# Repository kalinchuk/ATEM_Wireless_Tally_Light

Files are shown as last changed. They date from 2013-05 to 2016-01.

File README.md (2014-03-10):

# ATEM Wireless Tally Light

Wireless tally light system for ATEM switchers.

## Setup and Configuration

Note: We're assuming that you have a transmitter board with the Arduino Ethernet and also a receiver board with a JeeNode. If not, visit [http://kvitko.com/tally](http://kvitko.com/tally).

1.  Copy the dependent libraries from the project's libraries directory to your systems Arduino libraries directory. You may need to overwrite some of the libraries.
1.  Upload `ATEM_Tally_Receiver.ino` to your receiver node.
1.  Upload `ATEM_Tally_Transmitter.ino` to your transmitter.
1.  Connect the transmitter to the same network as the ATEM switcher and power it on (it may take a minute to connect to ATEM).
1.  Set the node # on your receiver using the DIP pins. It will blink the node # on power-on.

Once connected, the receiver will light up RED if on PROGRAM and GREEN if on PREVIEW.

## Transmitter

A transmitter transmits ATEM PROGRAM and PREVIEW camera numbers using an RF12 radio.

### Default Settings

	IP address		: 192.168.1.234
	Mac address 	: DE:AD:BE:EF:FE:ED
	Switcher IP		: 192.168.1.240
	Switcher PORT	: 49910

The settings can be modified using the web interface [http://192.168.1.234/](http://192.168.1.234/) or reset using the RESET button on the transmitter.

### LED States

The following are transmitter LED states:

	RED 		: Not connected to network (or ATEM switcher)
	BLUE 		: Connected to ATEM switcher
	RED BLINK	: Radio signal sent

## Receiver

A receiver receives radio signals from the transmitter and triggers either the PROGRAM LED or the PREVIEW LED according to the transmitter and ATEM.

### LED States

The following are receiver LED states:

	POWER-ON BLUE BLINK	: Blinks node # or rapidly for test mode
	CONSTANT BLUE BLINK	: In test mode (receiving radio signal)
	RED					: Node # is on PROGRAM
	GREEN				: Node # is on PREVIEW

### Test Mode

Setting the receiver's node # to 0 (all DIP pins off) will switch it to _test mode_. When in _test mode_ the receiver will blink BLUE every 1 second if it's receiving a radio signal. On power-on in _test mode_ the LED will blink BLUE rapidly for a second or so.

### Node DIP Pins

The node DIP pins are binary-based. For example, when the DIP pins are `0110`, the node # is `5`.

Note: The receiver needs to be restarted whenever the node # is changed.

## Library Modifications

The RF12 library was slightly modified to allow the Arduino Ethernet to support both the Ethernet and the RF12 radio. Since Ethernet and the radio both use the same `SS_BIT`, they will conflict with each other. Leave Ethernet as it is and modify the RF12 library only. 

Note: There is a new class called `RF12Mod` which is a copy of `RF12` with slight modifications.

## Credits

Based on the [Arduino ATEM Library](https://github.com/kasperskaarhoj/Arduino-Library-for-ATEM-Switchers)

## Contributing

We welcome any contributions and bug fixes. Feel free to send pull requests.

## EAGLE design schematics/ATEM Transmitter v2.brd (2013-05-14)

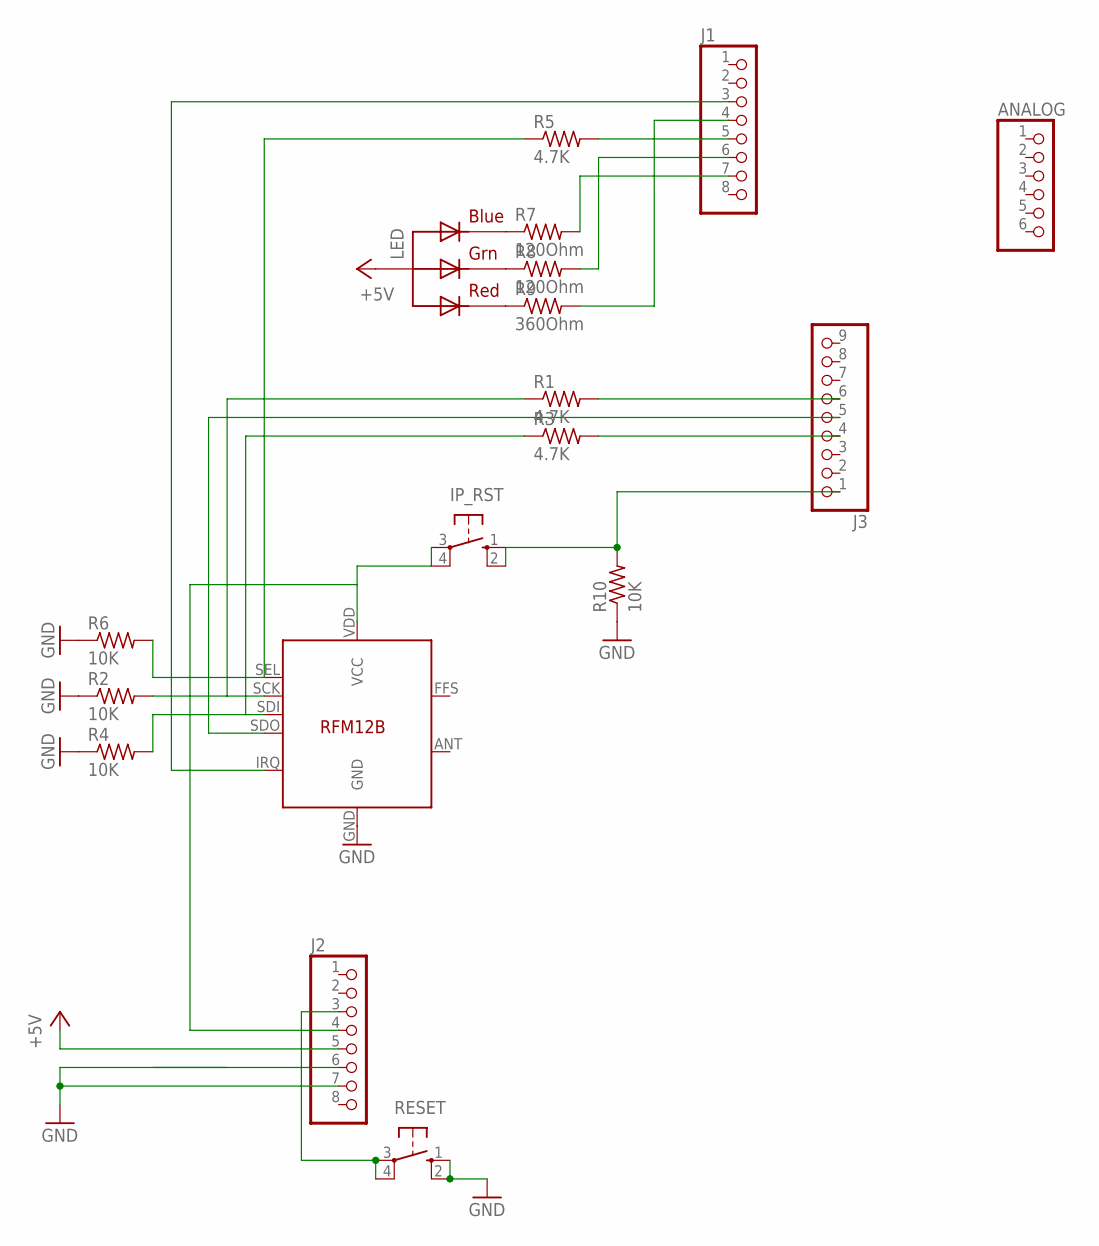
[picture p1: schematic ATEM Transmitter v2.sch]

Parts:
ANALOG: PINHD-1X6; 1X06
IP_RST: 10-XX; B3F-10XX
J1, J2: PINHD-1X8TH; 1X08-TH
J3: PINHD-1X9; 1X09
LED: RGBLED_CA-5MM; LED5MMRGB
R1, R3, R5: 4.7K; R0805
R2, R4, R6, R10: 10K; R0805
R7, R8: 120Ohm; R0805
R9: 360Ohm; R0805
RESET: 10-XX; B3F-10XX
U$2: RFM12B; LH-LIBRARY_RFM12B

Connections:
+5V: J2.5, LED.2 (VCC)
GND: J2.7, R2.1, R4.1, R6.1, R10.1, RESET.1 (S), RESET.2 (S1), U$2.GND
unnamed: IP_RST.3, IP_RST.4 (P1), J2.4, U$2.VDD (VCC)
unnamed: J3.6, R1.2
unnamed: R1.1, R2.2, U$2.SCK
unnamed: J1.3, U$2.IRQ
unnamed: R3.1, R4.2, U$2.SDI
unnamed: J3.4, R3.2
unnamed: J3.5, U$2.SDO
unnamed: R5.1, R6.2, U$2.SEL
unnamed: J1.5, R5.2
unnamed: LED.4 (BLUE), R7.1
unnamed: LED.3 (GREEN), R8.1
unnamed: LED.1 (RED), R9.1
unnamed: J1.4, R9.2
unnamed: IP_RST.1 (S), IP_RST.2 (S1), J3.1, R10.2
unnamed: J1.7, R7.2
unnamed: J1.6, R8.2
RESET: J2.3, RESET.3, RESET.4 (P1)

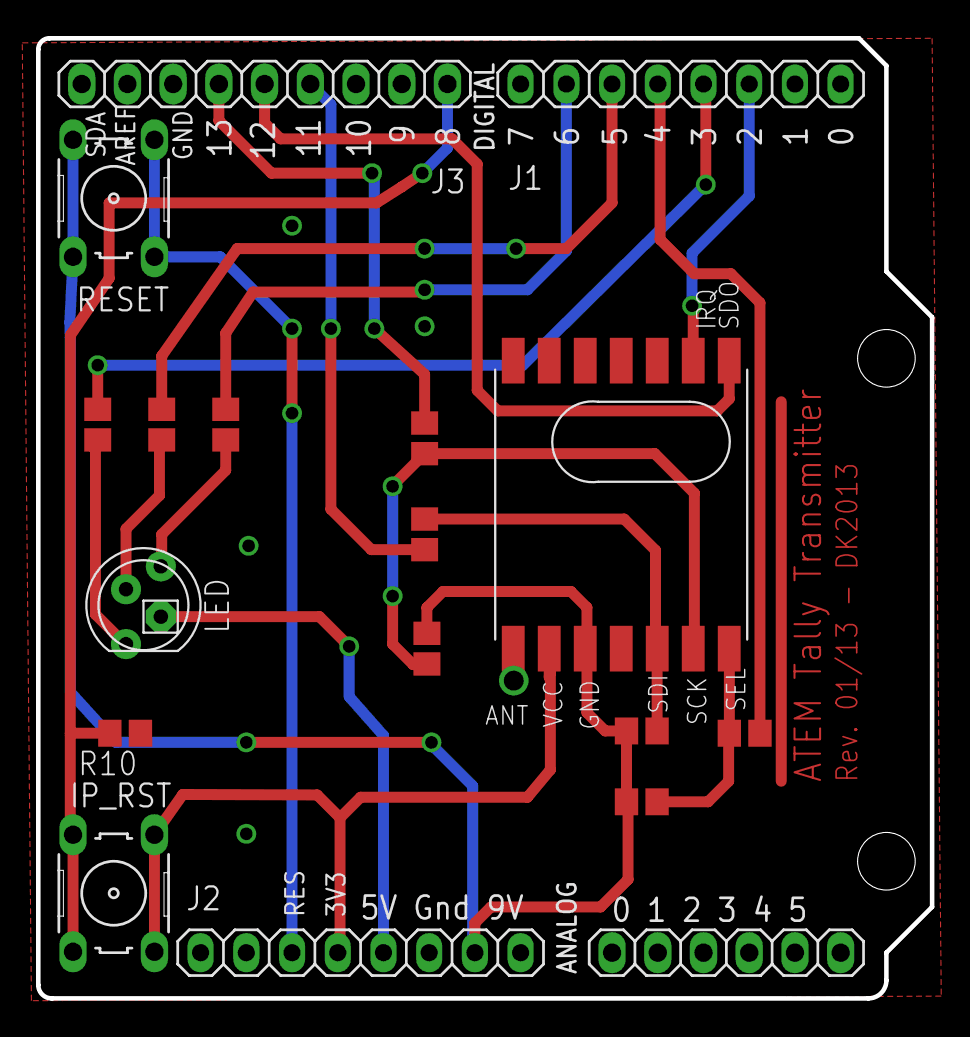
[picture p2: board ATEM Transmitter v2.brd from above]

Board: 2 copper layers, 49.7 x 53.3 mm, 18 parts (0 on the bottom side), 19 nets.

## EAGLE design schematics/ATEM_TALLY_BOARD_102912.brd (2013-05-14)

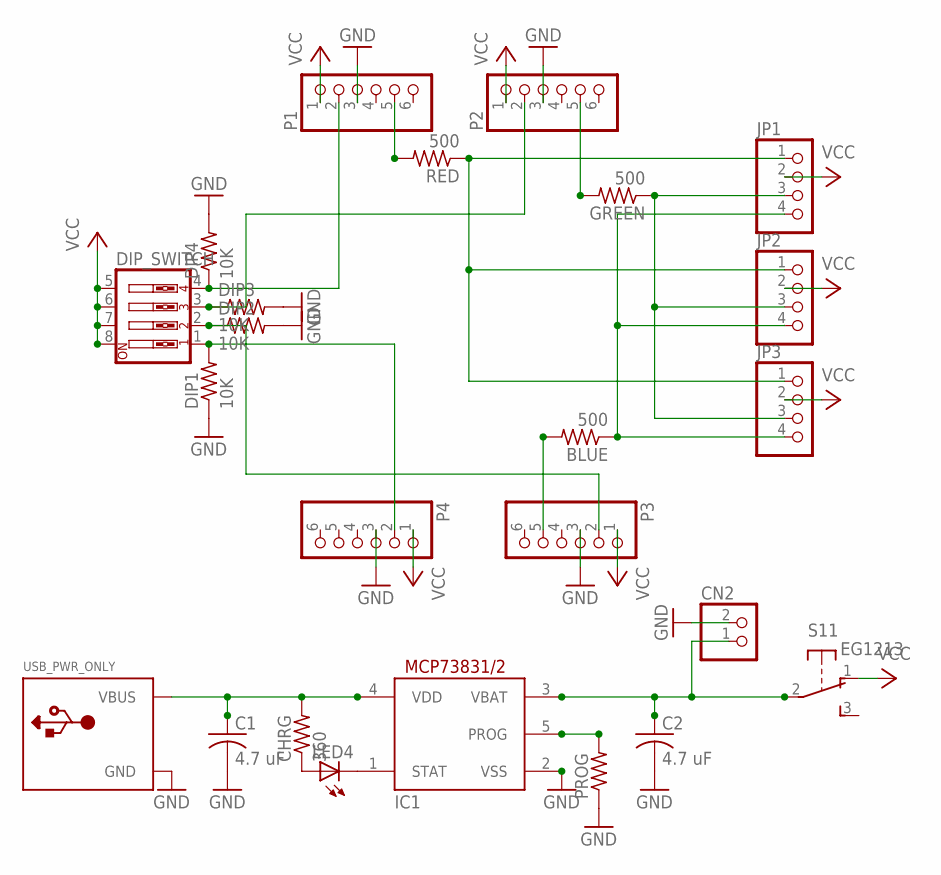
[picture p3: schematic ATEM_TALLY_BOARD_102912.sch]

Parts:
BLUE: 500; R0805
C1, C2: 4.7 uF; C0805K
CHRG: 360; R0805
CN2: JST_2PIN-SMT-RA; JST-PH-2-SMT-RA
DIP1, DIP2, DIP3, DIP4: 10K; R0805
DIP_SWITCH: SW_DIP-4; EDG-04
GREEN: 500; R0805
IC1: MCP73831/OT; SOT23-5L
JP1, JP2, JP3: PINHD-1X4; 1X04
LED4: LED3MM
P1, P2, P3, P4: PINHD-1X6CB; 1X06-CLEANBIG
PROG: R-US_R0805; R0805
RED: 500; R0805
S1: EG1213
USB_PWR_ONLY: USB-PWR-NOSILK; USB-MINIB-THM-MOLEX-PWRONLY-NOSILK

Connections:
BLUE: BLUE.1, JP1.4, JP2.4, JP3.4
GND: C1.2, C2.2, CN2.2 (1), DIP1.1, DIP2.2, DIP3.2, DIP4.2, IC1.2 (VSS), P1.3, P2.3, P3.3, P4.3, PROG.1, USB_PWR_ONLY.GND
GREEN: GREEN.1, JP1.3, JP2.3, JP3.3
unnamed: P1.5, RED.2
unnamed: GREEN.2, P2.5
unnamed: BLUE.2, P3.5
unnamed: C1.1, CHRG.2, IC1.4 (VDD), USB_PWR_ONLY.VBUS
unnamed: DIP4.1, DIP_SWITCH.4, P1.2
unnamed: DIP3.1, DIP_SWITCH.3, P2.2
unnamed: DIP2.1, DIP_SWITCH.2, P3.2
unnamed: DIP1.2, DIP_SWITCH.1, P4.2
unnamed: IC1.1 (STAT), LED4.K (C)
unnamed: CHRG.1, LED4.A
unnamed: IC1.5 (PROG), PROG.2
unnamed: C2.1, CN2.1 (2), IC1.3 (VBAT), S1.2
RED: JP1.1, JP2.1, JP3.1, RED.1
VCC: DIP_SWITCH.5, DIP_SWITCH.6, DIP_SWITCH.7, DIP_SWITCH.8, JP1.2, JP2.2, JP3.2, P1.1, P2.1, P3.1, P4.1, S1.1 (O)

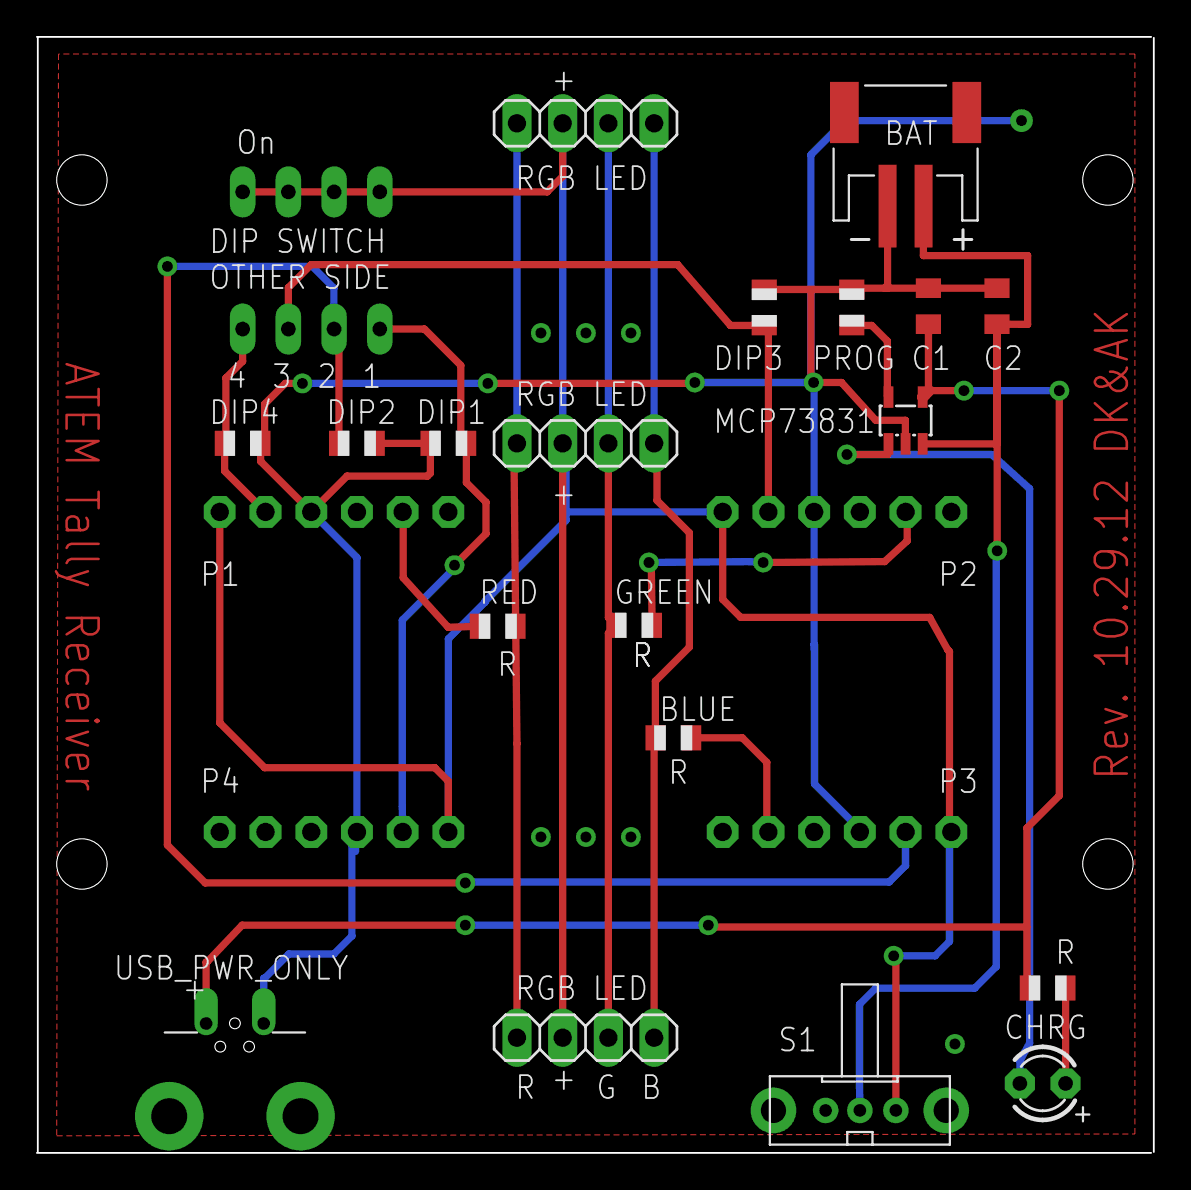
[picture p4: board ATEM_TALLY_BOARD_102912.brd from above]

Board: 2 copper layers, 62.0 x 62.0 mm, 24 parts (1 on the bottom side), 17 nets.

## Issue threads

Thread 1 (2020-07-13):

Misuse of Analog/digital pin functions

mwsfreak, 2020-07-13:
There seems to be a major misunderstanding in the use of AnalogWrite and DigitalWrite functions in ATEM_Tally_Receiver.ino

```C
int PROGRAM_PIN = A0;
int PREVIEW_PIN = A1;
int POWER_PIN = A2;
```
Led pins are set to Analog Input pins (l. 4+7+10). These pins are also capable of outputting digital signals, however not PWM signals.

```C
analogWrite(PROGRAM_PIN, 1023);
analogWrite(PREVIEW_PIN, 1023);
analogWrite(POWER_PIN, 1023);
```
Later (l. 50-52), an attempt is made to apparently output af PWM signal on these same pins.

```C
digitalWrite(PREVIEW_PIN, 1023);
digitalWrite(PROGRAM_PIN, 1023);
digitalWrite(POWER_PIN, 1023);
```
Further down, one attempts to write a value to a digital pin. The digitalwrite function only accepts HIGH and LOW.

The methods used probably works, but it seems quite far from the intended use of the functions.

kalinchuk, 2020-07-13:
@mwsfreak It may be a mistake. This repo is not being actively maintained. If you create a tested PR, I can merge it into master.

mwsfreak, 2020-07-13:
> @mwsfreak It may be a mistake. This repo is not being actively maintained. If you create a tested PR, I can merge it into master.

I can create a PR, but i unfortunately i don't have the hardware to test it.

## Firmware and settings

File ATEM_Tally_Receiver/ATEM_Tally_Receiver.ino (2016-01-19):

#include <JeeLib.h>

// PROGRAM LED pin
int PROGRAM_PIN = A0;

// PREVIEW LED pin
int PREVIEW_PIN = A1;

// POWER LED pin (blinks the node # on power up)
int POWER_PIN = A2;

// Node # DIP switch 1 pin
int DIP1_PIN = 4;

// Node # DIP switch 2 pin
int DIP2_PIN = 5;

// Node # DIP switch 3 pin
int DIP3_PIN = 6;

// Node # DIP switch 4 pin
int DIP4_PIN = 7;

// last received radio signal time (to power off LEDs when no signal)
unsigned long last_radio_recv = 0;

// default Node # 200 (alias to 0) will blink constantly if signal exists
int this_node = 200;

// The current program 1 camera number
int program_1;

// The current program 2 camera number
int program_2;

// The current preview number.
int preview;

void setup() {
	// initialize all the defined pins
	pinMode(PROGRAM_PIN, OUTPUT);
	pinMode(PREVIEW_PIN, OUTPUT);
	pinMode(POWER_PIN, OUTPUT);
	pinMode(DIP1_PIN, INPUT);
	pinMode(DIP2_PIN, INPUT);
	pinMode(DIP3_PIN, INPUT);
	pinMode(DIP4_PIN, INPUT);

	// turn all LEDs off (1023 is off)
  analogWrite(PROGRAM_PIN, 1023);
  analogWrite(PREVIEW_PIN, 1023);
  analogWrite(POWER_PIN, 1023);  
  
	// create an array of DIP pins
  int dipPins[] = {DIP1_PIN, DIP2_PIN, DIP3_PIN, DIP4_PIN};
  
	// set the Node # according to the DIP pins
  setNodeID(dipPins, 4);
  
	if (this_node == 200) {
		// if the Node # is 0 (alias to 200), blink quickly (30 times) on power on
		for (int i=0; i < 30; i++) {
			analogWrite(POWER_PIN, 0);
			delay(20);
			analogWrite(POWER_PIN, 1023);
			delay(20);
		}
	} else {
		// if the Node # is a set number, blink the Node # on power on
		for (int i=0; i < this_node; i++) {
			analogWrite(POWER_PIN, 0);
			delay(300);
			analogWrite(POWER_PIN, 1023);
			delay(300);
		}
	}
  
	// set this variable to current time
  last_radio_recv = millis();
}

void loop() {
	if (rf12_recvDone() && rf12_crc == 0 && rf12_len >= 1) {
		// a radio signal was received
		
		// get the program and preview numbers
		program_1 = rf12_data[0];
		program_2 = rf12_data[2];
    preview = rf12_data[4];

		// turn off all LEDs
		digitalWrite(PREVIEW_PIN, 1023);
		digitalWrite(PROGRAM_PIN, 1023);
		digitalWrite(POWER_PIN, 1023);

		if (this_node == 200) {
			// if the Node # is 200 (which is also 0), blink POWER LED every 1 second if signal exists
			digitalWrite(POWER_PIN, 0);
			delay(1000);
			digitalWrite(POWER_PIN, 1023);
			delay(1000);
		} else {
			// if the Node # is a set number, trigger an LED accordingly
			if (program_1 == this_node || program_2 == this_node) {
				digitalWrite(PREVIEW_PIN, 1023);
				analogWrite(PROGRAM_PIN, 0);
			} else if (preview == this_node) {
				analogWrite(PROGRAM_PIN, 1023);
				digitalWrite(PREVIEW_PIN, 0);
			}
		}
		
		// keep track of last radio signal time
		last_radio_recv = millis();
	}
  
	// turn off LEDs when no radio signal exists (the past 1 second)
	if (millis() - last_radio_recv > 1000) {
		digitalWrite(PREVIEW_PIN, 1023);
		digitalWrite(PROGRAM_PIN, 1023);
		digitalWrite(POWER_PIN, 1023);
	}
}

// reads the DIP switches and determines the Node #
byte setNodeID(int* dipPins, int numPins) {
	float j=0;
  
	for(int i=0; i < numPins; i++) {
		if (digitalRead(dipPins[i])) {
			j += pow(2, i);
		}
	}

  this_node = (int)(j + 0.5);

	// if the DIP switches are all OFF, assign 200 (alias to 0) to the Node #
  this_node = this_node == 0 ? 200 : this_node;

	// initialize the radio
  rf12_initialize(this_node, RF12_433MHZ, 4);
}

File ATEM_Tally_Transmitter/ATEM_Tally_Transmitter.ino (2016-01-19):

#include <SPI.h>
#include <Ethernet.h>
#include <TextFinder.h>
#include <EEPROM.h>
#include <avr/pgmspace.h>
#include <ATEMstd.h>
#include <ATEMTally.h>
#include <JeeLibMod.h>

// set the default MAC address
byte mac[] = { 0xDE, 0xAD, 0xBE, 0xEF, 0xFE, 0xED};

// set the default IP address
byte ip[] = {192,168,1,234};

// set the default IP address of the ATEM switcher
byte switcher_ip[] = {192,168,1,240};

// set the default PORT of the ATEM switcher
long switcher_port = 49910;

// initialize the ethernet server (for settings page)
EthernetServer server(80);

// set to false initially; set to true when ATEM switcher initializes
boolean ranOnce = false;

// create a new AtemSwitcher and ATEMTally object
ATEMstd AtemSwitcher;
ATEMTally ATEMTally;

// Define variables for determining whether tally is on
boolean programOn;
boolean previewOn;

// define a structure for sending over the radio
struct {
	int program_1;
	int program_2;
	int preview;
} payload;

void setup()
{
	// initialize the RF12 radio; set the Node # to 20
	RF12Mod_initialize(20, RF12Mod_433MHZ, 4);

	// initialize the ATEMTally object
	ATEMTally.initialize();
	
	// set the LED to RED
	ATEMTally.change_LED_state(2);
	
	// setup the Ethernet
	ATEMTally.setup_ethernet(mac, ip, switcher_ip, switcher_port);
	
	// start the server
	server.begin();

	// delay a bit before looping
	delay(1000);
}

void loop()
{
	// run this code only once
	if (!ranOnce) {
		// initialize the AtemSwitcher
		AtemSwitcher.begin(IPAddress(switcher_ip[0], switcher_ip[1], switcher_ip[2], switcher_ip[3]), switcher_port);    
		
		// attempt to connect to the switcher
		AtemSwitcher.connect();

		// change LED to RED
		ATEMTally.change_LED_state(2);
		
		ranOnce = true;
	}

	// display the setup page if requested
	EthernetClient client = server.available();
	ATEMTally.print_html(client, mac, ip, switcher_ip, switcher_port);

	// AtemSwitcher function for retrieving the program and preview camera numbers
	AtemSwitcher.runLoop();

	// if connection is gone anyway, try to reconnect
	if (AtemSwitcher.hasInitialized())  {
		// Reset the previous program and preview numbers
		payload.program_1 = 0;
		payload.program_2 = 0;
		payload.preview = 0;

		// assign the program and preview numbers to the payload structure
		for (int i = 1; i <= 16; i++) {
			programOn = AtemSwitcher.getProgramTally(i);
			previewOn = AtemSwitcher.getPreviewTally(i);

			if (programOn) {
				if (payload.program_1 == 0) {
					payload.program_1 = i;
				} else {
					payload.program_2 = i;
				}
			}

			if (previewOn) {
				payload.preview = i;
			}
		}
		
		// when radio is available, transmit the structure with program and preview numbers
		RF12Mod_recvDone();
		if (RF12Mod_canSend()) {
			RF12Mod_sendStart(0, &payload, sizeof payload);
			ATEMTally.change_LED_state(3);
		}
	}

	// a delay is needed due to some weird issue
	delay(10);

	ATEMTally.change_LED_state(1);

	// monitors for the reset button press
	ATEMTally.monitor_reset();
}

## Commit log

2013-05-14 Schematic and board files added
    [ATEM Transmitter v2.brd, ATEM Transmitter v2.sch, ATEM_TALLY_BOARD_102912.brd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]
2016-01-19 Compile on Arduino IDE 1.6.7. Fix bugs including bug where two programs should be on during transition. Upgrade to ATEMstd.
    [ATEM_Tally_Receiver.ino, ATEM_Tally_Transmitter.ino]
